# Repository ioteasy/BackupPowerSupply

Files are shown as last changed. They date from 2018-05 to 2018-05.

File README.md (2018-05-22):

# BackupPowerSupply
Module for backup power supply with 18650 - Li-ion battery

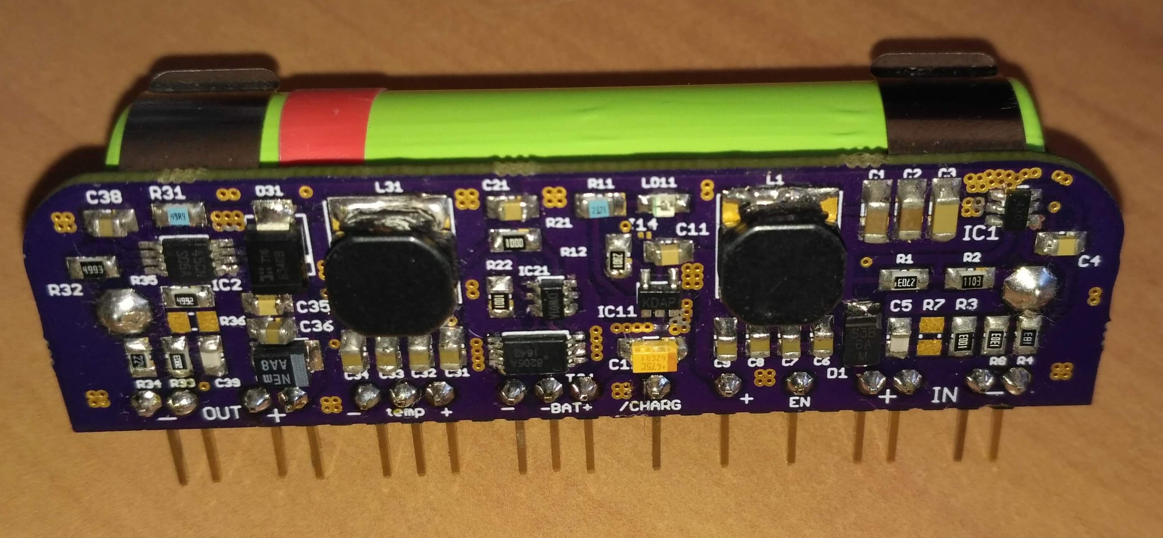
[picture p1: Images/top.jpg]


## Parameters
Input voltage: 5-24V

Output voltage Normal State: 4.4V

Output voltage Battery State: 4.3V

Max Current: 1A

## Used components
TPS54302 - Step-Down Converter (Input 4.5V-28V), Integrated MOSFETs for 3A continuous output current

LM2621 - Step-Up Converter (Input 1.2V-14V), Switch Current Limit 2.8A, Max switching frequenc 2MHz

MCP73831 - Single Cell Li-Ion Charge Management 

DW01 - Li-Ion Battery Protection

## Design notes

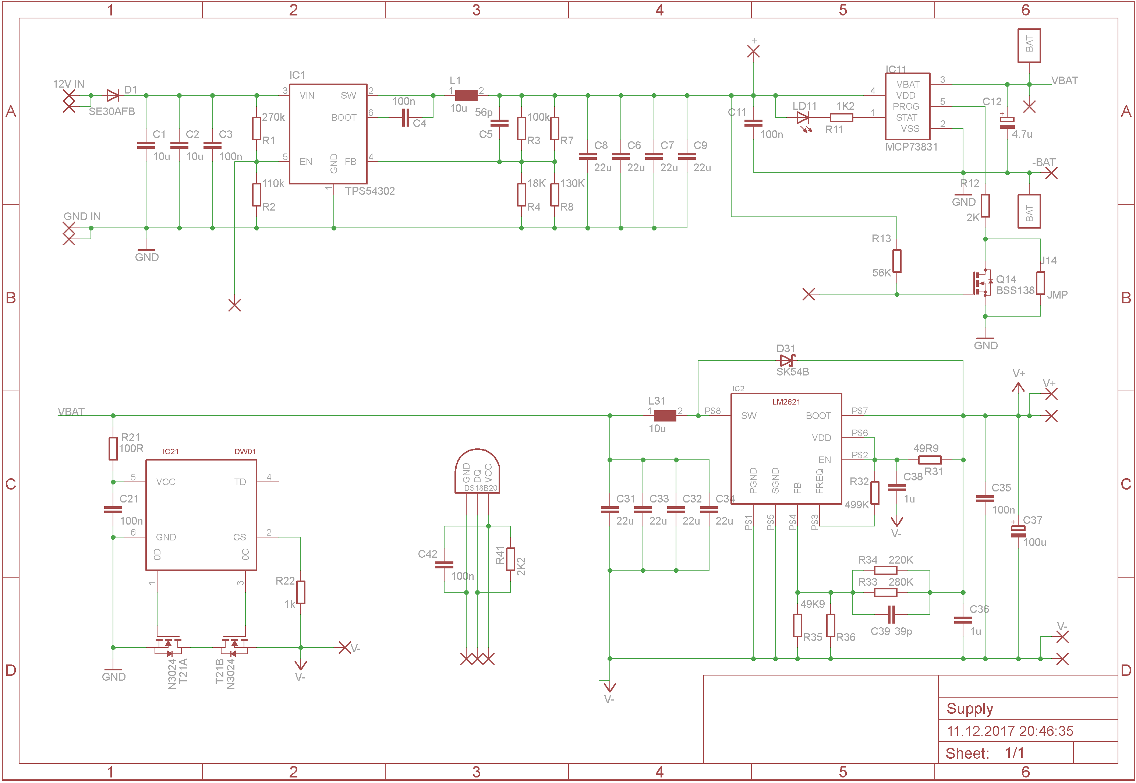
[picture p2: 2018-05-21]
Schematics/Schematic.png

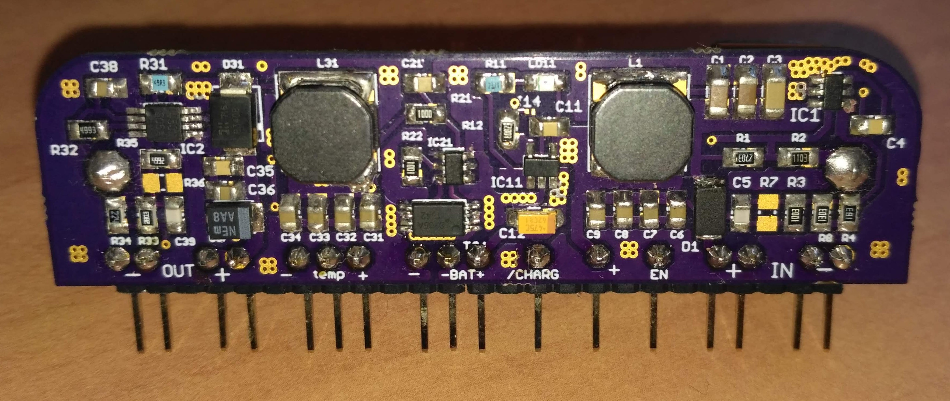
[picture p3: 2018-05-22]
Images/Front.jpg

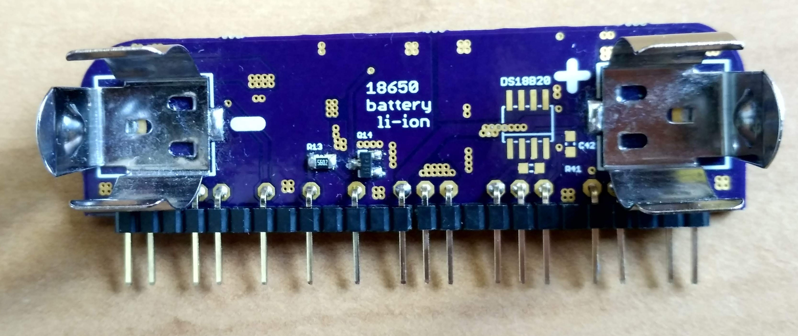
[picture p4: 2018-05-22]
Images/Back.jpg

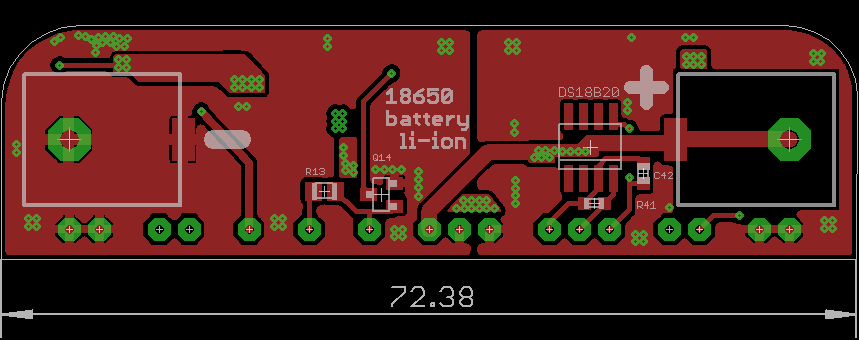
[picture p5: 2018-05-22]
Pcb/top.png

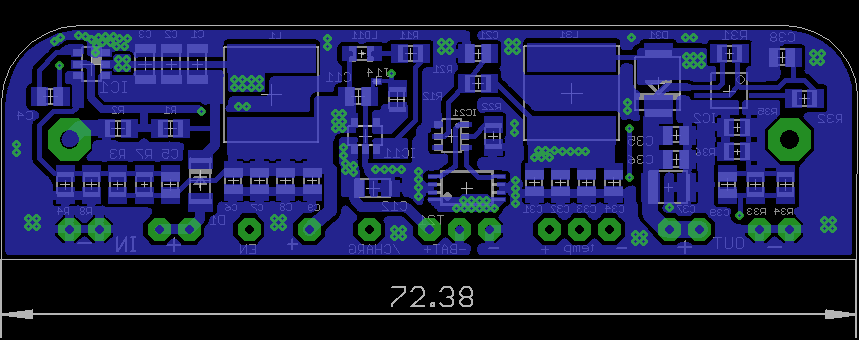
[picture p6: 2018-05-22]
Pcb/bot.png

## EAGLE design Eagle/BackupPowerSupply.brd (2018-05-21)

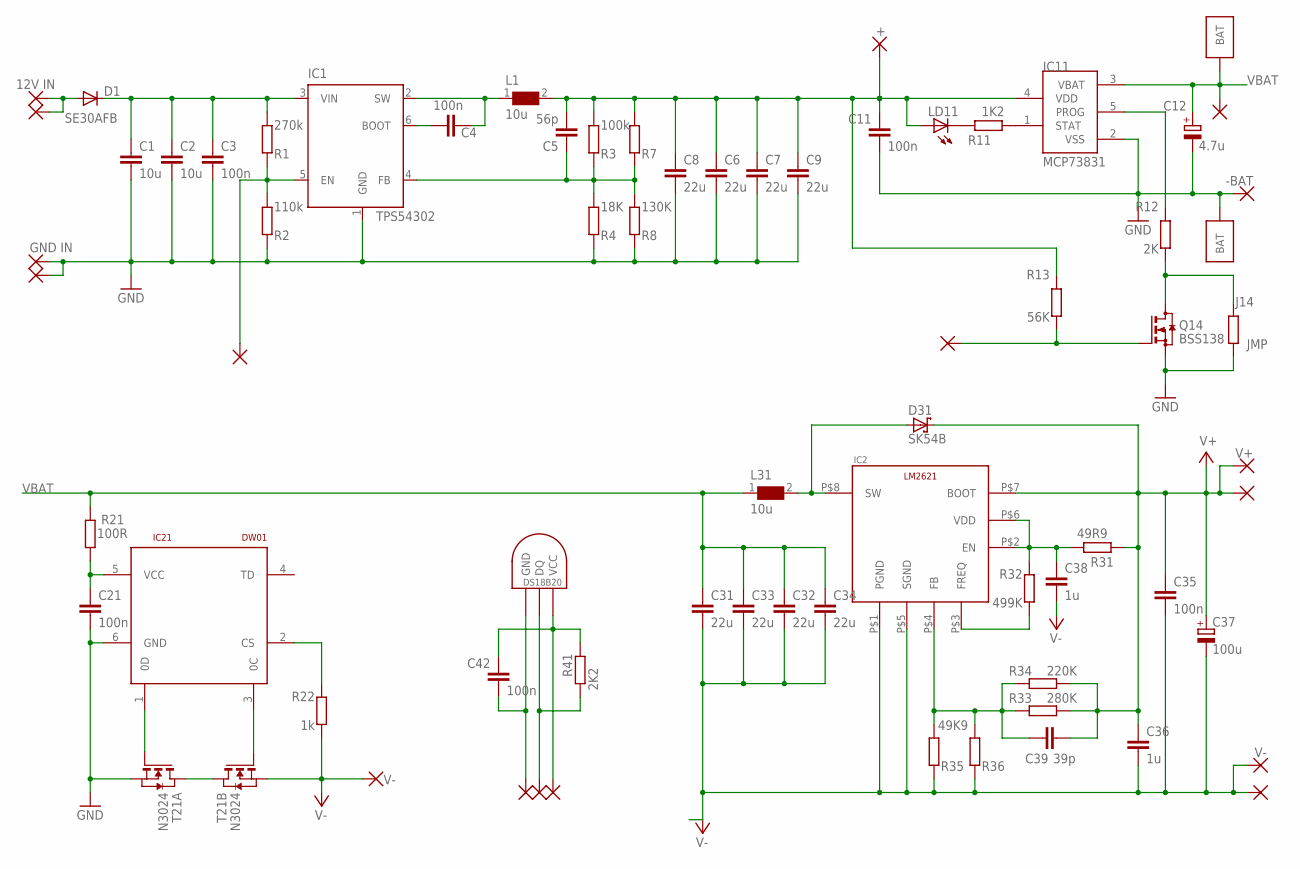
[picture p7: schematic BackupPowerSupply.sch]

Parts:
C1, C2: 10u; C1206
C3: 100n; C1206
C4, C11, C21, C35: 100n; C0805
C5: 56p; C0805
C6, C7, C8, C9, C31, C32, C33, C34: 22u; C0805
C12: 4.7u; SMC_A
C36, C38: 1u; C0805
C37: 100u; SMC_B
C39: 39p; C0805
C42: 100n; C0603
D1: SE30AFB; SOD-123_MINI-SMA
D31: SK54B; SMB
DS18B20: DS1820SOIC; DS18B20_SOIC
IC1: TPS54302; TSOT23-6_DDC
IC2: LM2621VSSOP8; VSSOP8
IC11: MCP73831; SOT23-5L
IC21: DW01; SOT23-6
J14: JMP; R0201
L1, L31: 10u; WE-LQS_8040
LD11: LEDCHIPLED_0805; CHIPLED_0805
PAD1: +BAT; PAD
PAD2: -BAT; PAD
PAD3: 12V IN; PAD
PAD4: GND IN; PAD
PAD5, PAD12: V+; PAD
PAD6, PAD9, PAD11, PAD19, PAD20, PAD21: V-; PAD
PAD7, PAD13: +; PAD
PAD8, PAD22: PAD
Q14: BSS138; SOT23
R1: 270k; M0805
R2: 110k; M0805
R3: 100k; M0805
R4: 18K; M0805
R7, R36: R-EU_M0805; M0805
R8: 130K; M0805
R11: 1K2; M0805
R12: 2K; M0805
R13: 56K; M0805
R21: 100R; M0805
R22: 1k; M0805
R31: 49R9; M0805
R32: 499K; M0805
R33: 280K; M0805
R34: 220K; M0805
R35: 49K9; M0805
R41: 2K2; R0603
T21: N3024; TSSOP-8
U$1, U$2: BAT_A
U$3: PAD

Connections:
C6: C5.2, IC1.4 (FB), R3.2, R4.1, R7.2, R8.1
FB2: C39.1, IC2.P$4 (FB), R33.1, R34.1, R35.1, R36.1
GND: C1.1, C2.1, C3.1, C6.1, C7.1, C8.1, C9.1, C11.1, C12.-, C21.1, IC1.1 (GND), IC11.2 (VSS), IC21.6 (GND), J14.1, PAD2.P$1, PAD4.P$1, PAD8.P$1, Q14.2 (S), R2.2, R4.2, R8.2, T21.2 (S), T21.3 (S), U$2.P$1, U$2.P$4
unnamed: C4.2, IC1.6 (BOOT)
unnamed: C42.1, DS18B20.GND, PAD21.P$1
unnamed: PAD7.P$1, Q14.1 (G), R13.1
unnamed: J14.2, Q14.3 (D), R12.1
unnamed: C5.1, C6.2, C7.2, C8.2, C9.2, C11.2, IC11.4 (VDD), L1.2, LD11.A, PAD13.P$1, R3.1, R7.1, R13.2
unnamed: IC11.1 (STAT), R11.1
unnamed: IC1.5 (EN), PAD22.P$1, R1.2, R2.1
unnamed: D1.A, PAD3.P$1, U$3.P$1
unnamed: IC11.5 (PROG), R12.2
unnamed: IC21.3 (0C), T21.5 (G)
unnamed: LD11.C, R11.2
unnamed: IC21.1 (0D), T21.4 (G)
unnamed: C38.2, IC2.P$2 (EN), IC2.P$6 (VDD), R31.2, R32.2
unnamed: IC2.P$3 (FREQ), R32.1
unnamed: T21.1 (D), T21.8 (D)
unnamed: IC21.2 (CS), R22.2
unnamed: DS18B20.DQ, PAD19.P$1, R41.2
unnamed: C21.2, IC21.5 (VCC), R21.1
unnamed: C42.2, DS18B20.VCC, PAD20.P$1, R41.1
OUT_DOWN: C4.1, IC1.2 (SW), L1.1
V+: C35.2, C36.2, C37.+, C39.2, D31.C, IC2.P$7 (BOOT), PAD5.P$1, PAD12.P$1, R31.1, R33.2, R34.2
V-: C31.1, C32.1, C33.1, C34.1, C35.1, C36.1, C37.-, C38.1, IC2.P$1 (PGND), IC2.P$5 (SGND), PAD6.P$1, PAD9.P$1, PAD11.P$1, R22.1, R35.2, R36.2, T21.6 (S), T21.7 (S)
VBAT: C12.+, C31.2, C32.2, C33.2, C34.2, IC11.3 (VBAT), L31.1, PAD1.P$1, R21.2, U$1.P$1, U$1.P$4
VIN_DOWN: C1.2, C2.2, C3.2, D1.C, IC1.3 (VIN), R1.1
VSW: D31.A, IC2.P$8 (SW), L31.2

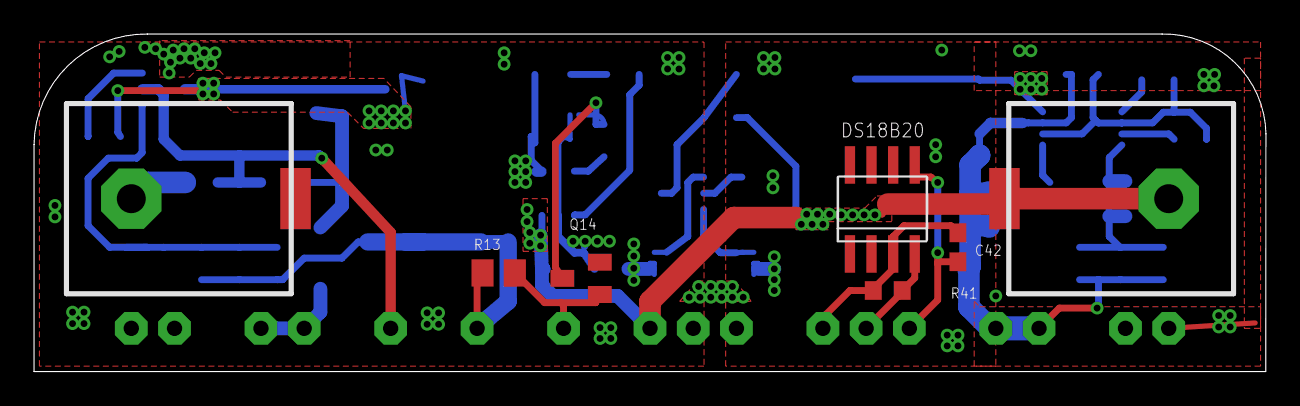
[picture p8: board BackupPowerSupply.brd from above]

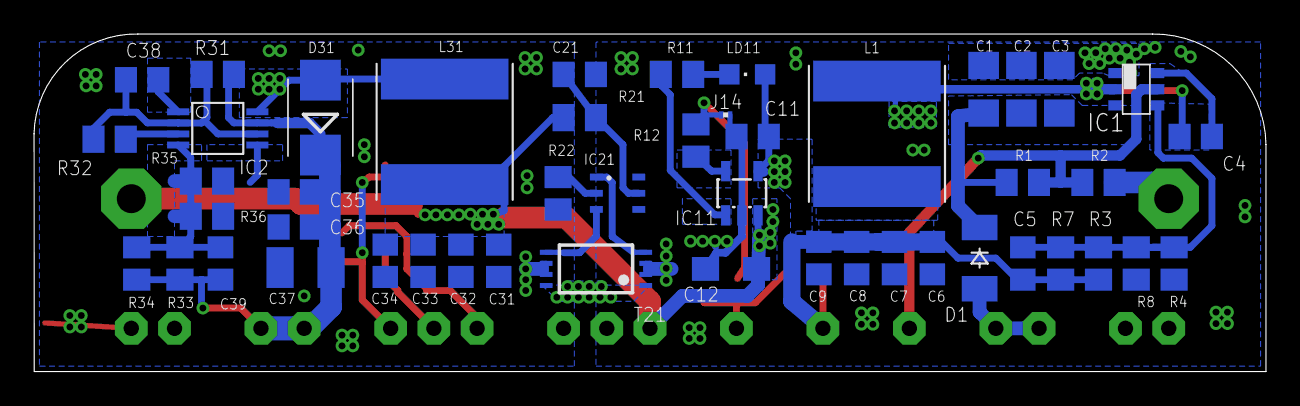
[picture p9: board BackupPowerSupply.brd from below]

Board: 2 copper layers, 72.4 x 19.8 mm, 72 parts (48 on the bottom side), 28 nets.

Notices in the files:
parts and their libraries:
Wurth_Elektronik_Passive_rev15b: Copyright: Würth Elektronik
